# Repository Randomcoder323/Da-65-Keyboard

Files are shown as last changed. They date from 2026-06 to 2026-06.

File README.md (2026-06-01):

# Da-65-Keyboard

## What
This is my first full keyboard, and I chose for it to be 65%. It features 67 keys with hotswap. A diode for each each along with a RGB led on the bottom. The 3d print requires no hardware. I added a level changer for the leds too! Its powered by an esp32 for lots of power. I had so much fun making this and learned lots of new stuff about electronics and pcbs.
## Why
I made this to improve my pcb making skills. I used lots of new items like the stablizers and how to layout siwtches succesfully.
## PICS







Screenshot 2026-05-25 at 9 02 06 PM
Screenshot 2026-05-25 at 9 01 53 PM


## BOM

| Name | Purpose | Quantity | Total Cost (USD) | Link | Distributor |
|---|---|---|---|---|---|
| Silicon feet | to avoid the keyboard slipping | 1 | 2.56 | https://a.aliexpress.com/_mO4IA6b | Aliexpress  |
| Solder | To hold the components, I'm running out | | 4.36 | https://a.aliexpress.com/_mKav2EF | Aliexpress  |
| Kailh Hot-swap Sockets | Hot-swap switch mounting | 67 | 7.96 | https://a.aliexpress.com/_mtMnHRv | AliExpress  |
| SK6812 Mini-E LEDs | Per-key RGB lighting | 67 | 3.88 | https://a.aliexpress.com/_msnVr4L | AliExpress  |
| MX Stabilizers (6.25u + 2u) | Stabilize large keys | 3 | 3.29 | https://a.aliexpress.com/_mqkGaMB | AliExpress  |
| ESP32-S3-DevKitC-1 N16R8 | Microcontroller | 1 | 4.77 | https://a.aliexpress.com/_mNGX0qx | AliExpress  |
| 1N4148WS SOD-323 Diodes | Switch matrix diodes | 67 | 1.91 | https://a.aliexpress.com/_m0JBedh | AliExpress  |
| 65% Keycap Set | Keycaps | 1 | 10.43 | https://a.aliexpress.com/_mqke2HZ | AliExpress  |
| Custom PCB | Main keyboard PCB | 1 | 36.39 | https://jlcpcb.com | JLCPCB |
| 3D Printed Case | Holds all components | 1 | 3.00 | | Self |
| 74AHCT125 SOIC-14 | LED level shifter | 1 | 2.95 | https://a.aliexpress.com/_mte1tpN | AliExpress  |
| Cherry MX Switches | Key switches | 67 | 9.48 | https://a.aliexpress.com/_mO8yt4x | AliExpress  |

**Total** $93.38 (with taxes)

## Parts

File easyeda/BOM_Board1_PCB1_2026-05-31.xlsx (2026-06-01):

No. | Quantity | Comment | Designator | Footprint | Value | Manufacturer Part | Manufacturer | Supplier Part | Supplier
1 | 67 | 1N4148 | D1,D2,D3,D4,D5,D6,D7,D8,D9,D10,D11,D12,D13,D14,D15,D16,D17,D18,D19,D20,D21,D22,D23,D24,D25,D26,D27,D28,D29,D30,D31,D32,D33,D34,D35,D36,D37,D38,D39,D40,D41,D42,D43,D44,D45,D46,D47,D48,D49,D50,D51,D52,D53,D54,D55,D56,D57,D58,D59,D61,D62,D63,D64,D66,D67,D68,D69 | SOD-323_L1.8-W1.3-LS2.5-RD |  | 1N4148WS T4 | CJ | C2128 | LCSC
2 | 1 | CherryMX Stabilizer 6.25U | STB_1 | CHERRYMX STABILIZER 6.25U |  | Cherry MX Stabilizer 6.25
3 | 2 | G99-0742 | STB_2,STB_3 | CHERRYMX STABILIZER 2U |  | G99-0742 |  | 540-G99-0742 | Mouser
4 | 67 | SW_Push | SW1,SW2,SW3,SW4,SW5,SW6,SW7,SW8,SW9,SW10,SW11,SW12,SW13,SW14,SW15,SW16,SW17,SW18,SW19,SW20,SW21,SW22,SW23,SW24,SW25,SW26,SW27,SW28,SW29,SW30,SW31,SW33,SW34,SW35,SW36,SW37,SW38,SW39,SW40,SW43,SW44,SW45,SW46,SW47,SW48,SW49,SW50,SW51,SW52,SW53,SW54,SW55,SW56,SW57,SW58,SW59,SW60,SW61,SW62,SW63,SW64,SW65,SW66,SW67,SW68,SW69,SW70 | CherryMX_PCB_KailhSocket_LTST-A683CEGBW:CherryMX_1.00u_PCB_KailhSocket_LTST-A683CEGBW
5 | 1 | CPG151101S11 | U3 | TH_L11.0-W5.9-KS-2P02B01-01 |  | CPG151101S11 |  | C9900013508 | LCSC
6 | 1 | ESP32-S3-DEVKITC-1-N8 | U5 | CONN-TH_ESP32-S3-DEVKITC-1U-N8 |  | ESP32-S3-DEVKITC-1-N8 | ESPRESSIF(乐鑫) | C20438410 | LCSC
7 | 67 | SK6812MINI-E | U77,U78,U79,U80,U81,U82,U83,U84,U85,U86,U87,U88,U89,U90,U91,U92,U93,U94,U95,U96,U97,U98,U99,U100,U101,U102,U103,U104,U105,U106,U107,U108,U109,U110,U111,U112,U113,U114,U115,U116,U117,U118,U119,U120,U121,U122,U123,U124,U125,U126,U127,U128,U129,U130,U131,U132,U133,U134,U135,U136,U137,U138,U139,U140,U141,U142,U143 | SK6812MINI-E
8 | 1 | 74AHCT125D,112 | U147 | SOP-14_L8.6-W3.9-P1.27-LS6.0-BL |  | 74AHCT125D,112 | Nexperia(安世) | C554501 | LCSC

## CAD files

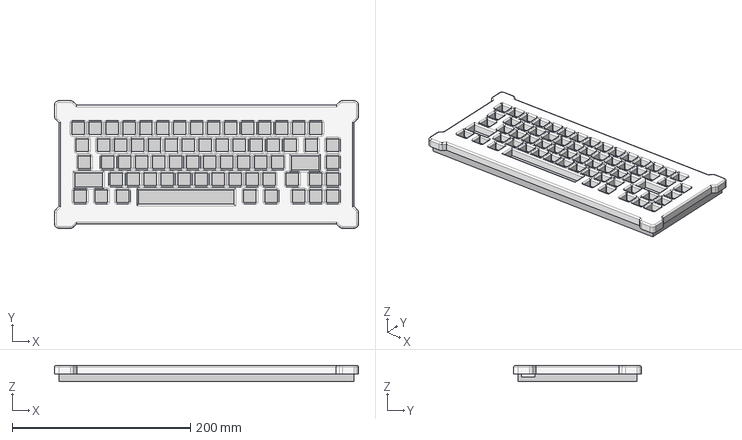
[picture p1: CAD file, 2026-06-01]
CAD/Keyboard case.step
341.2 x 143.3 x 18.4 mm

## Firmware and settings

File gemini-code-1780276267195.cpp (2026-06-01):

#include "USB.h"
#include "USBHIDKeyboard.h"
#include <FastLED.h>

USBHIDKeyboard Keyboard;

const int NUM_ROWS = 5;
const int NUM_COLS = 14;

byte rowPins[NUM_ROWS] = {4, 5, 6, 7, 15}; 
byte colPins[NUM_COLS] = {1, 2, 3, 8, 9, 10, 11, 12, 13, 14, 16, 17, 18, 21};

#define LED_DATA_PIN   47
#define LED_POWER_PIN  3   
#define NUM_LEDS       68  
CRGB leds[NUM_LEDS];

uint16_t keymap[NUM_ROWS][NUM_COLS] = {
  {KEY_ESC, '1', '2', '3', '4', '5', '6', '7', '8', '9', '0', '-', '=', KEY_BACKSPACE},
  {KEY_TAB, 'q', 'w', 'e', 'r', 't', 'y', 'u', 'i', 'o', 'p', '[', ']', KEY_DELETE},
  {KEY_CAPS_LOCK, 'a', 's', 'd', 'f', 'g', 'h', 'j', 'k', 'l', ';', '\'', KEY_RETURN, KEY_PAGE_UP},
  {KEY_LEFT_SHIFT, 'z', 'x', 'c', 'v', 'b', 'n', 'm', ',', '.', '/', KEY_RIGHT_SHIFT, KEY_UP_ARROW, KEY_PAGE_DOWN},
  {KEY_LEFT_CTRL, KEY_LEFT_GUI, KEY_LEFT_ALT, ' ', ' ', ' ', KEY_RIGHT_ALT, KEY_RIGHT_CTRL, KEY_LEFT_ARROW, KEY_DOWN_ARROW, KEY_RIGHT_ARROW, 0, 0, 0}
};

bool keyState[NUM_ROWS][NUM_COLS];

void setup() {
  Serial.begin(115200);
  
  pinMode(LED_POWER_PIN, OUTPUT);
  digitalWrite(LED_POWER_PIN, LOW); 

  FastLED.addLeds<WS2812B, LED_DATA_PIN, GRB>(leds, NUM_LEDS);
  FastLED.setBrightness(50); 
  fill_solid(leds, NUM_LEDS, CRGB::Cyan); 
  FastLED.show();

  Keyboard.begin();
  USB.begin();

  for (int r = 0; r < NUM_ROWS; r++) {
    pinMode(rowPins[r], INPUT_PULLUP);
  }

  for (int c = 0; c < NUM_COLS; c++) {
    pinMode(colPins[c], OUTPUT);
    digitalWrite(colPins[c], HIGH);
  }

  for (int r = 0; r < NUM_ROWS; r++) {
    for (int c = 0; c < NUM_COLS; c++) {
      keyState[r][c] = false;
    }
  }
}

void loop() {
  for (int c = 0; c < NUM_COLS; c++) {
    digitalWrite(colPins[c], LOW);
    delayMicroseconds(30); 

    for (int r = 0; r < NUM_ROWS; r++) {
      bool isPressed = (digitalRead(rowPins[r]) == LOW);

      if (isPressed && !keyState[r][c]) {
        keyState[r][c] = true;
        if (keymap[r][c] != 0) {
          Keyboard.press(keymap[r][c]);
        }
      } 
      else if (!isPressed && keyState[r][c]) {
        keyState[r][c] = false;
        if (keymap[r][c] != 0) {
          Keyboard.release(keymap[r][c]);
        }
      }
    }

    digitalWrite(colPins[c], HIGH);
  }

  uint8_t thisHue = beatsin8(15, 0, 255); 
  fill_rainbow(leds, NUM_LEDS, thisHue, 4);
  FastLED.show();
  
  delay(2); 
}
